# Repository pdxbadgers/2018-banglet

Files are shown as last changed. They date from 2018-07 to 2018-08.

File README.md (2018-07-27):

DEFCON 26 DC503 VIP Banglet
---------------------------
Here we are, another crazy year, another crazy party badge.  Necks are so over-used, so this year we're migrating to the wrist.  The idea is a fully functional bluetooth recon device with multiple, um, "hidden" party modes on the bleuart (like, UART over bluetooth, crazy right?) service.

credits (github/twitter)
------------------------

Original Concept:
* @nishakm / @nishakmr

Board Design:
* @nishakm / @nishakmr
* @r00tkillah

3D Design:
* @jonhannis
* @pierce403 / @deanpierce

PCB necromancers:
* @r00tkillah
* @securelyfitz
* @office_deskjet
* @nishakm / @nishakmr
* @jonhannis

Code monkeys:
* @pierce403 / @deanpierce
* @nishakm / @nishakmr

Special thanks to Adafruit Industries for publishing their board designs, 3D designs and NRF52 Arduino code examples.

And a special thanks to everyone else who donated time, money, or crazy ideas that helped make this possible.

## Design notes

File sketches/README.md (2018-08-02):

Welcome to the 503 Party
------------------------
So, you have a 503 banglet, now what?  You may notice a striking similarity to the Adafruit Feather.  This is because the banglet board is pretty much a Feather modified to fit the banglet form factor. What that means is that A0 is the only data pin you have access to and it goes straight to a neopixel strip. But you still have the whole suite of BT functionality that the Nordic NRF52 SoC has to offer. So you'll have to get creative with encoding your data into blinky lights ;).

Adafruit has a good collection of examples to get you started with writing your custom sketch. You can clone their repo here: https://github.com/adafruit/Adafruit_NRF52_Arduino

These instructions will take you through flashing your own custom arduino sketch to your banglet.

Installing the Feather board definitions
----------------------------------------

Paraphrased from here:

https://learn.adafruit.com/adafruit-feather-32u4-basic-proto/arduino-ide-setup

Download Arduino for your platform:

https://www.arduino.cc/en/Main/Software

In preferences add "Additonal Boards Manager URLs":

https://adafruit.github.io/arduino-board-index/package_adafruit_index.json

Tools > Board > Board Manager

Search for "Adafruit nrf52 by Adafruit"

Install the latest.

Restart Arduino IDE

Toors > Board > Adafruit Feather 32u4

Installing the Neo Pixel library
--------------------------------
To light up the neopixels, you need to install the Neo Pixel libraries.  Luckily you should be able to find it pretty quick in the library manager.

Sketch > Include Libraries > Manage Libraries

Adafruit Neo Pixel

You will need 32 bit glibc
and install nrfutil

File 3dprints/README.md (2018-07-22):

503 Banglet STL files
---------------------

You may notice there is a soft and a hard version.  The soft design was the original design, and has a much more rubbery feel.  The recommended filament for the soft design is the clear flexible filament from 3Dsolutech.com.  This can be a huge pain to print on most 3D printers, so we also made a version of the banglet with a hinge.  This banglet can be printed with standard PLA or ABS.

Once printed, you can press fit or glue magnets into the holes, depending on version printed, and maybe put some 22 gauge wire into the hinge if you printed the hard version.  We have also been using thin bands of 3/4" clear polyolefin heat shrink tubing to hold the electronics in place.

Recommended printer settings:
---------------------------
soft banglet:
```
0.2mm layer height
100% infill
230c extruder temp
```

hard banglet:
```
0.2mm layer height
10% hexagonal infill
230c extruder temp
55-90c bed temp (depends on filament)
```

Big thanks to @jonhannis for leading this effort.

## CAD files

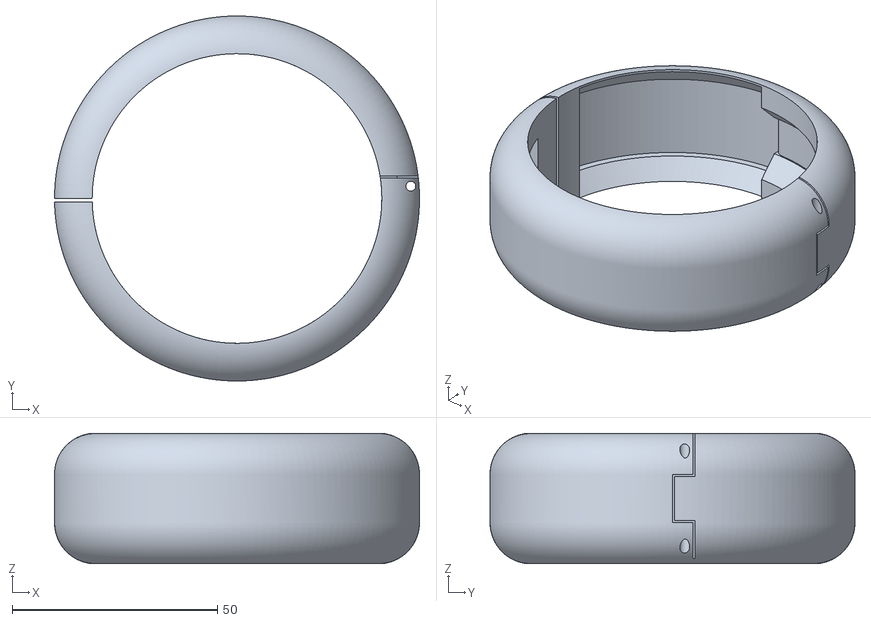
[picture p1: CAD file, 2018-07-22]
3dprints/503banglet-hard.stl
88.9 x 88.9 x 31.8

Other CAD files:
3dprints/503banglet-soft.stl

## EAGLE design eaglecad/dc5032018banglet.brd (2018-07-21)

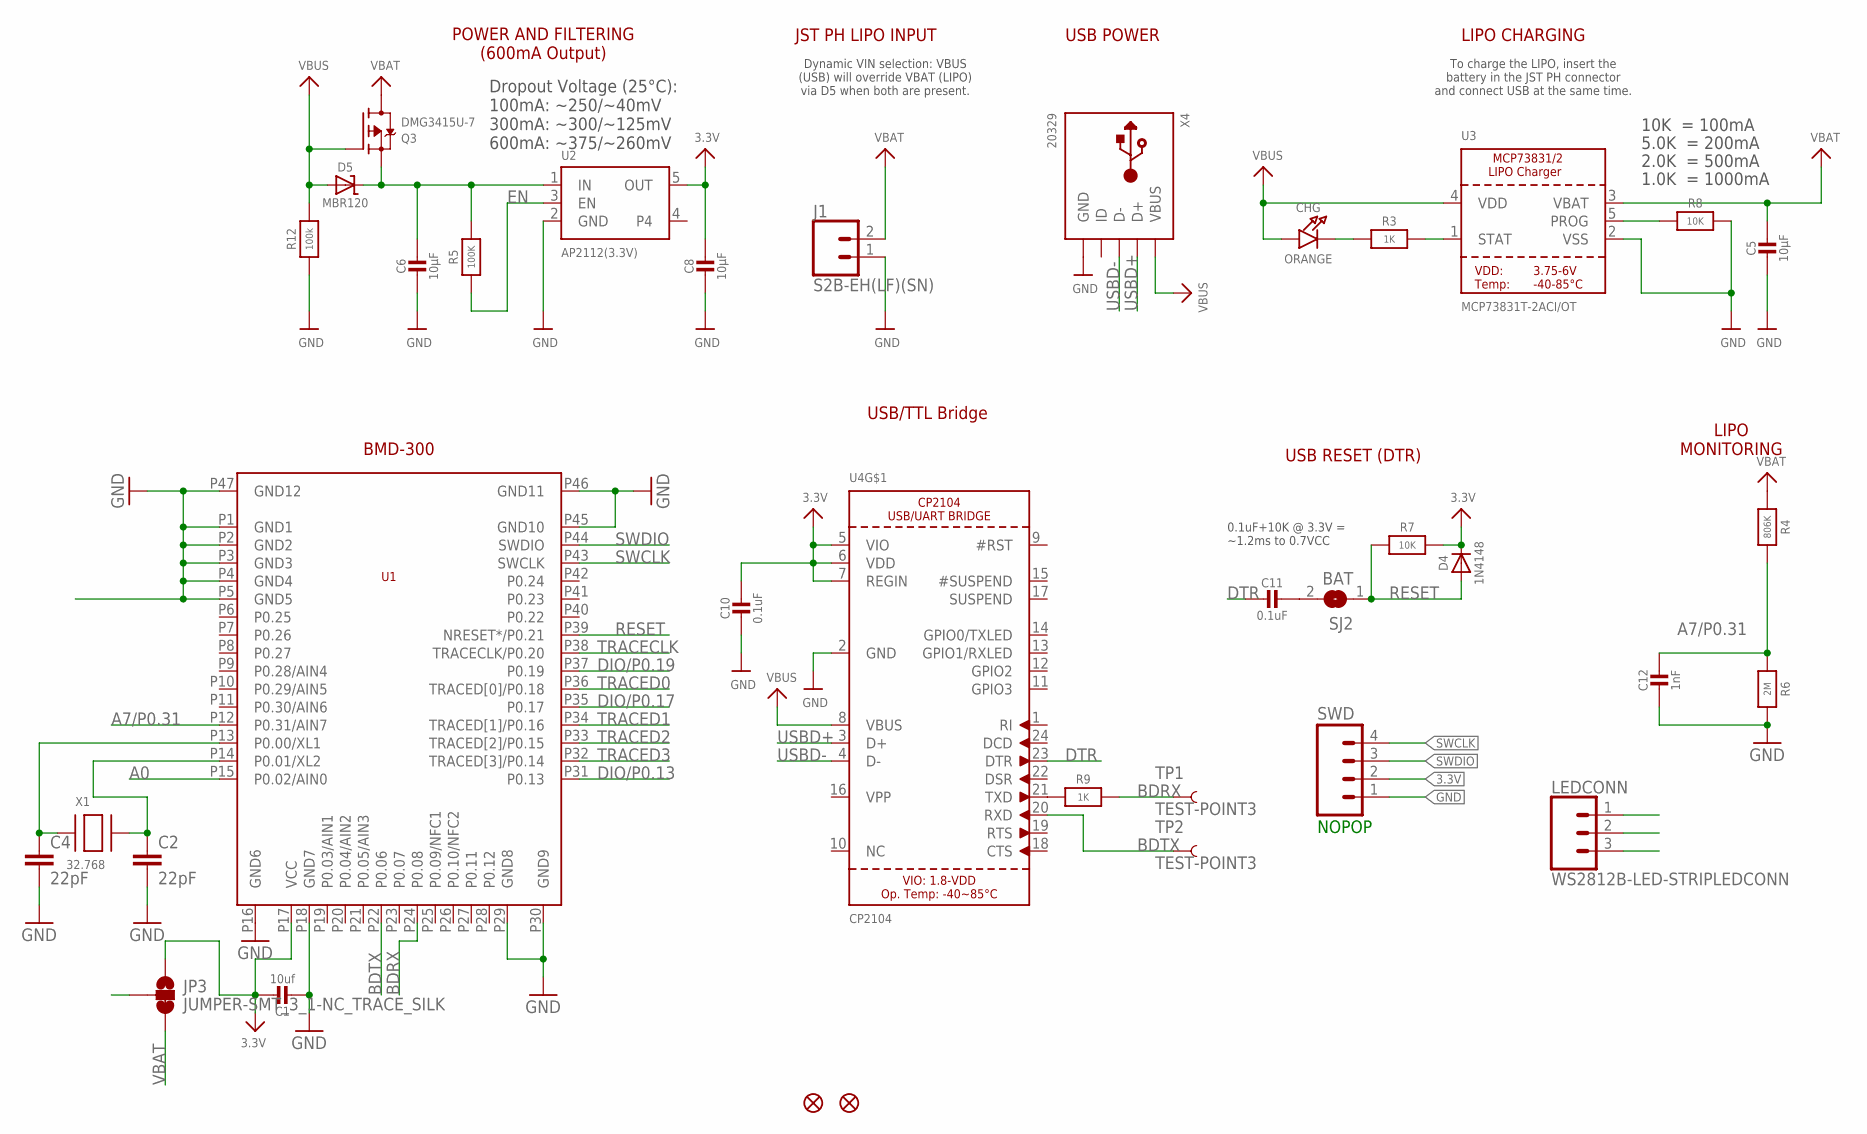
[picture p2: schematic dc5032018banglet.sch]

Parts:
C1: 10uf; 0805-NO
C2, C4: 22pF; 0603
C5, C6, C8: 10µF; 0805-NO
C10, C11: 0.1uF; 0603-NO
C12: 1nF; 0603-NO
CHG: ORANGE; CHIPLED_0805_NOOUTLINE
D4: 1N4148; SOD-323
D5: MBR120; SOD-123
FD1, FD2: FIDUCIALUFIDUCIAL; FIDUCIAL-MICRO
J1: S2B-EH(LF)(SN); 1X2(2.5)
JP3: JUMPER-SMT_3_1-NC_TRACE_SILK; SMT-JUMPER_3_1-NC_TRACE_SILK
LEDCONN: WS2812B-LED-STRIPLEDCONN; 1X3(2.5)
Q3: DMG3415U-7; SOT23-R
R3, R9: 1K; 0603-NO
R4: 806K; 0603-NO
R5: 100K; 0603-NO
R6: 2M; 0603-NO
R7, R8: 10K; 0603-NO
R12: 100k; 0603-NO
SJ2: BAT; SOLDERJUMPER_CLOSEDWIRE
SWD: M04LOCK; 1X04_LOCK@1
TP1, TP2: TEST-POINT3; PAD.03X.03
U1: BMD-300
U2: AP2112(3.3V); SOT23-5
U3: MCP73831T-2ACI/OT; SOT23-5
U4: CP2104; QFN24_4MM_SMSC
X1: 32.768; XTAL3215
X4: 20329; MICRO-USB5+6P-SMD-0.65-B

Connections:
3.3V: C1.1, C8.1, C10.1, D4.C, JP3.1, R7.2, SWD.2, U1.P17 (VCC), U2.5 (OUT), U4.5 (VIO), U4.6 (VDD), U4.7 (REGIN)
A0: LEDCONN.2, U1.P15 (P0.02/AIN0)
A7/P0.31: C12.1, R4.2, R6.1, U1.P12 (P0.31/AIN7)
BDRX: R9.2, TP1.P$1, U1.P24 (P0.08)
BDTX: TP2.P$1, U1.P22 (P0.06), U4.20 (RXD)
DIO/P0.13: U1.P31 (P0.13)
DIO/P0.17: U1.P35 (P0.17)
DIO/P0.19: U1.P37 (P0.19)
DTR: C11.2, U4.23 (DTR)
EN: R5.1, U2.3 (EN)
GND: C1.2, C2.2, C4.2, C5.2, C6.2, C8.2, C10.2, C12.2, J1.1, LEDCONN.3, R6.2, R8.2, R12.1, SWD.1, U1.P1 (GND1), U1.P2 (GND2), U1.P3 (GND3), U1.P4 (GND4), U1.P5 (GND5), U1.P16 (GND6), U1.P18 (GND7), U1.P29 (GND8), U1.P30 (GND9), U1.P45 (GND10), U1.P46 (GND11), U1.P47 (GND12), U2.2 (GND), U3.2 (VSS), U4.2 (GND), X4.5 (GND), X4.S1 (GND), X4.S2 (GND), X4.S3 (GND), X4.S4 (GND), X4.S5 (GND), X4.S6 (GND)
unnamed: C2.1, U1.P14 (P0.01/XL2), X1.P$2
unnamed: C4.1, U1.P13 (P0.00/XL1), X1.P$1
unnamed: CHG.C, R3.1
unnamed: R3.2, U3.1 (STAT)
unnamed: R8.1, U3.5 (PROG)
unnamed: R9.1, U4.21 (TXD)
unnamed: C11.1, SJ2.2
RESET: D4.A, R7.1, SJ2.1, U1.P39 (NRESET*/P0.21)
SWCLK: SWD.4, U1.P43 (SWCLK)
SWDIO: SWD.3, U1.P44 (SWDIO)
TP: U4.THERM (TP)
TRACECLK: U1.P38 (TRACECLK/P0.20)
TRACED0: U1.P36 (TRACED[0]/P0.18)
TRACED1: U1.P34 (TRACED[1]/P0.16)
TRACED2: U1.P33 (TRACED[2]/P0.15)
TRACED3: U1.P32 (TRACED[3]/P0.14)
USBD+: U4.3 (D+), X4.3 (D+)
USBD-: U4.4 (D-), X4.2 (D-)
VBAT: C5.1, J1.2, JP3.3, Q3.3 (D), R4.1, U3.3 (VBAT)
VBUS: CHG.A, D5.A, Q3.1 (G), R12.2, U3.4 (VDD), U4.8 (VBUS), X4.1 (VBUS)
VIN: C6.1, D5.C, Q3.2 (S), R5.2, U2.1 (IN)
VLED: JP3.2, LEDCONN.1

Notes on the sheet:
POWER AND FILTERING (600mA Output)
Dropout Voltage (25°C): 100mA: ~250/~40mV 300mA: ~300/~125mV 600mA: ~375/~260mV
JST PH LIPO INPUT
Dynamic VIN selection: VBUS (USB) will override VBAT (LIPO) via D5 when both are present.
USB POWER
10K = 100mA
5.0K = 200mA
2.0K = 500mA
1.0K = 1000mA
LIPO CHARGING
To charge the LIPO, insert the battery in the JST PH connector and connect USB at the same time.
LIPO MONITORING
USB RESET (DTR)
0.1uF+10K @ 3.3V = ~1.2ms to 0.7VCC
USB/TTL Bridge
NOPOP
BMD-300

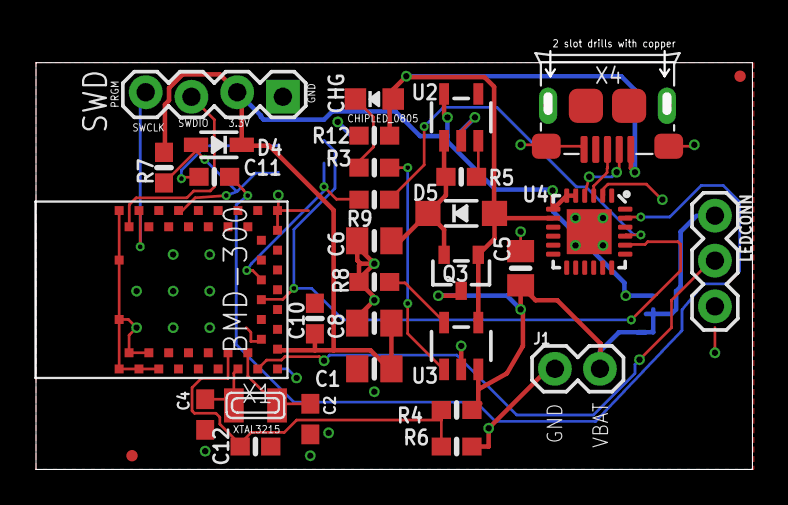
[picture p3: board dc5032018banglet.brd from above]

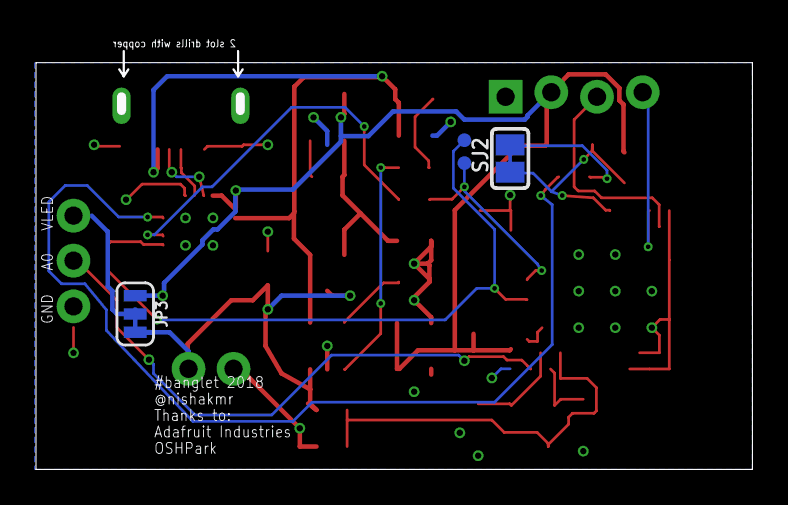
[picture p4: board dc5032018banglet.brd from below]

Board: 2 copper layers, 39.8 x 23.2 mm, 36 parts (4 on the bottom side), 24 nets.

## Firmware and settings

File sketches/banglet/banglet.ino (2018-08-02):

/*********************************************************************
 This is an example for our nRF52 based Bluefruit LE modules

 Pick one up today in the adafruit shop!

 Adafruit invests time and resources providing this open source code,
 please support Adafruit and open-source hardware by purchasing
 products from Adafruit!

 MIT license, check LICENSE for more information
 All text above, and the splash screen below must be included in
 any redistribution
*********************************************************************/

/*********************************************************************
 * Thank you, Adafruit Industries for the examples!
 *
 * This is the sketch that makes the Banglet work
 * It came from https://github.com/pdxbadgers/2018-banglet/
 * There are other sketches there so if you would like to flash the
 * other ones to see what they do or try to hack on your banglet, feel
 * free to clone the project and follow the instructions
 *
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
 * This is meant to be used with either the Adafruit Bluefruit LE app
 * or the Serial Bluetooth Terminal. It takes advantage of Nordic's
 * proprietary UART service, allowing you to interact with the banglet
 * using a 'shell'. You can find these apps at the Android play store
 * (I am not sure about iOS but I am guessing you can find an equivalent)
 *
 * Once you connect to the banglet, you can list all the commands by sending
 * '/list' through the terminal.
 *
 * Happy Hacking!
 ************************************************************************/

#include <bluefruit.h>
#include <Adafruit_NeoPixel.h>
#include "wdt.h"
#include "CRC32.h"

/*
 * Global
 */

// BLE Service
BLEUart bleuart;

String mode="scan"; // set the default mode

// BT device scan
uint seen=0;
const byte MAX_MACS = 24;
uint8_t* seen_macs[MAX_MACS];
uint8_t* seen_names[MAX_MACS];


// neopixel
#define N_LEDS 12
#define PIN    A0

Adafruit_NeoPixel strip = Adafruit_NeoPixel(N_LEDS, PIN, NEO_GRB + NEO_KHZ800);

// unique names
const String direc[] = {"NE",
                        "NW",
                        "SE",
                        "SW",
                        "N",
                        "S",
                        "E",
                        "W"};

const String loc[] = {"Alder",
                      "Burnside",
                      "Couch",
                      "Davis",
                      "Everett",
                      "Flanders",
                      "Glisan",
                      "Hoyt",
                      "Irving",
                      "Johnson",
                      "Kirby",
                      "Lovejoy",
                      "Marshall",
                      "Northrup",
                      "Overton",
                      "Pettygrove",
                      "Quimby",
                      "Raleigh",
                      "Savier",
                      "Thurman",
                      "Upshur",
                      "Vaughn",
                      "Wilson",
                      "York"};

const String st[] = {"Street",
                     "Avenue",
                     "Way",
                     "Place"};

/*
 * Initial setup
 */
void setup()
{
  // turn off watchdog during setup
  wdt_disable();
  
  // setup serial
  Serial.begin(115200);
  Serial.println("Welcome to your Banglet!");
  Serial.println("---------------------------\n");


  // create banglet's name
  char* uniqueID = (char*)getMcuUniqueID();
  Serial.printf("id: %s\r\n",uniqueID);
  uint32_t checksum = CRC32::calculate((const char*)(uniqueID), strlen(uniqueID));
  Serial.printf("checksum: %u\r\n",checksum);
  randomSeed(checksum);
  
  String leading = "503 ";
  String banglet_name = leading + direc[random(0, 8)] + " " + loc[random(0,24)] + " " + st[random(0, 4)];
  char char_b_name[30];
  banglet_name.toCharArray(char_b_name, 30);
  Serial.printf("name: %s\r\n",char_b_name);
  Serial.println();

  // setup strip
  stripInit();

  // allocate some buffers
  for(int i=0;i<MAX_MACS;++i)
  {
    uint8_t* new_thing = new uint8_t[6];
    uint8_t* new_name  = new uint8_t[32];
    memset(new_thing,0,6);
    memset(new_name,0,32);
    seen_macs[i]=new_thing;
    seen_names[i]=new_name;
  }

  // Config the peripheral connection with maximum bandwidth
  // more SRAM required by SoftDevice
  // Note: All config***() function must be called before begin()
  Bluefruit.configPrphBandwidth(BANDWIDTH_MAX);

  Bluefruit.begin();
  // Set max power. Accepted values are: -40, -30, -20, -16, -12, -8, -4, 0, 4
  Bluefruit.setTxPower(4);
  Bluefruit.setName(char_b_name);
  Bluefruit.setConnectCallback(connect_callback);
  Bluefruit.setDisconnectCallback(disconnect_callback);

  // Start Central Scan
  Bluefruit.setConnLedInterval(250);
  Bluefruit.Scanner.setRxCallback(scan_callback);
  //Bluefruit.Scanner.filterRssi(-80);
  Bluefruit.Scanner.start(0);

  // Configure and Start BLE Uart Service
  bleuart.begin();

  // Set up and start advertising
  startAdv();

  Serial.println("Please use the Adafruit Bluefruit app or the Serial Bluetooth Terminal app to connect to the Banglet");
  Serial.println("Once connected, send /list for a list of commands you can send");

  // set up the watchdog
  wdt_enable(WDTO_8S);
}

// advertise peripheral BLEUART service
void startAdv(void)
{
  // Advertising packet
  Bluefruit.Advertising.addFlags(BLE_GAP_ADV_FLAGS_LE_ONLY_GENERAL_DISC_MODE);
  Bluefruit.Advertising.addTxPower();

  // Include bleuart 128-bit uuid
  Bluefruit.Advertising.addService(bleuart);

  // Secondary Scan Response packet (optional)
  // Since there is no room for 'Name' in Advertising packet
  Bluefruit.ScanResponse.addName();

  /* Start Advertising
   * - Enable auto advertising if disconnected
   * - Interval:  fast mode = 20 ms, slow mode = 152.5 ms
   * - Timeout for fast mode is 30 seconds
   * - Start(timeout) with timeout = 0 will advertise forever (until connected)
   *
   * For recommended advertising interval
   * https://developer.apple.com/library/content/qa/qa1931/_index.html
   */
  Bluefruit.Advertising.restartOnDisconnect(true);
  Bluefruit.Advertising.setInterval(32, 244);    // in unit of 0.625 ms
  Bluefruit.Advertising.setFastTimeout(30);      // number of seconds in fast mode
  Bluefruit.Advertising.start(0);                // 0 = Don't stop advertising after n seconds
}

// show that the strip is on
void stripInit(){
  strip.begin();
  strip.setBrightness(16);
  for(int i=0;i<strip.numPixels(); i++){
    strip.setPixelColor(i, strip.Color(255, 0, 0));
    strip.show();
    delay(100);
    strip.setPixelColor(i, strip.Color(0, 0, 0));
    strip.show();
  }
}


// find mac addresses
int find_mac(uint8_t* mac)
{
  for(int i=0;i<seen;++i)
  {
    if(0==memcmp(mac,seen_macs[i],6))
    {
      return i;
    }
  }
  //seen_macs[seen]=mac;
  memcpy(seen_macs[seen%MAX_MACS],mac,6);
  seen++;

  return seen-1;
}

// scan callback function which prints out mac
// addresses in a readable way
void scan_callback(ble_gap_evt_adv_report_t* report)
{
  uint8_t new_thing[6];
  memcpy(new_thing,report->peer_addr.addr,6);
  //Serial.println("copied MAC buffer");

  // which device is this?
  //Serial.println("finding thing");
  int thing = find_mac(new_thing);
  //Serial.printf("found thing %d\n",thing);

  uint8_t new_name[32];
  memset(new_name,0,32);
  if(Bluefruit.Scanner.parseReportByType(report, BLE_GAP_AD_TYPE_COMPLETE_LOCAL_NAME, new_name, 32))
  {
    if(strlen((char*)new_name)>0)
    {
      memset(seen_names[thing],0,32);
      memcpy(seen_names[thing],new_name,32);
    }
  }

}


/*
 * Loop function
 * Read bytes send from UART app and do stuff with it
 */
void loop()
{
  wdt_reset(); // kick the watchdog timer
  delay(200);  // short nap
  
  // Forward from BLEUART to HW Serial
  while ( bleuart.available() )
  {
    char rx_buf[64];
    memset(rx_buf,0,sizeof(rx_buf));
    int rx_size = bleuart.read(rx_buf, sizeof(rx_buf));
    String command = String(rx_buf);
    command.trim();
    parseCommand(command);
  }

  if(mode.equals("scan"))btscan();
  else if(mode.equals("rainbow"))rainbow(10, 1);
  else if(mode.equals("patriot"))patriot();
  else if(mode.equals("off"))turnOff();
  else if(mode.equals("frozen"))blueScaleFade(200);
  else if(mode.equals("fire"))redScaleFade(200);
  else btscan(); // I guess scan should be the default

  // Request CPU to enter low-power mode until an event/interrupt occurs
  waitForEvent();
}

// UART service connect callback
void connect_callback(uint16_t conn_handle)
{
  char central_name[32] = { 0 };
  Bluefruit.Gap.getPeerName(conn_handle, central_name, sizeof(central_name));

  Serial.print("Connected to ");
  Serial.println(central_name);
  //listCommands();
}

// UART service disconnect callback
void disconnect_callback(uint16_t conn_handle, uint8_t reason)
{
  (void) conn_handle;
  (void) reason;

  Serial.println();
  Serial.println("Disconnected");
}

/*
 * Main Banglet functions that parses the send messages and does things with it
 */
void parseCommand(String command)
{
  if(command.equals("help"))listCommands();
  else if(command.equals("devices"))listDevices();
  else if(command.equals("count"))numDevices();
  else if(command.equals("modes"))listModes();

  // some LED modes
  else if(command.equals("scan"))scan();
  else if(command.equals("off"))off();
  else if(command.equals("rainbow"))rainbow();
  else if(command.equals("patriot"))setPatriot();
  else if(command.equals("frozen"))frozen();
  else if(command.equals("fire"))fire();

  // just for fun
  else if(command.equals("id")){bleuart.write("uid=0(root) gid=0(root)");bleuart.write("groups=0(root)\n");}

  // brightness options
  else if(command.equals("bright"))strip.setBrightness(16);
  else if(command.equals("brighter"))strip.setBrightness(32);
  else if(command.equals("brightest"))strip.setBrightness(64);
  else if(command.equals("blinding"))strip.setBrightness(128);
  else
  {
    bleuart.write("Unknown command, ");
    bleuart.write("type 'help' for help.\n");
  }
  bleuart.write("\n# ");
}

/*
 * All the things Banglet can do
 * You can either hack these or add your function here
 */

// list all commands
void listCommands()
{
  bleuart.write("help: You're looking");
  bleuart.write(" at it.\n");

  bleuart.write("devices: List known");
  bleuart.write(" devices.\n");

  bleuart.write("count: List number of");
  bleuart.write(" devices.\n");

  bleuart.write("modes: List banglet");
  bleuart.write(" display modes.\n");
}

// list all modes
void listModes()
{
  bleuart.write("scan: Show bt");
  bleuart.write(" devices.\n");
  bleuart.write("off: No lights.\n");

  if(seen<5)
  {
    bleuart.write("????: Unlock at level 5.\n");
    bleuart.write("Collect more BT devices to unlock modes!");
    return;
  }

  bleuart.write("patriot: OMG USA!\n");
  
  if(seen<10)
  {
    bleuart.write("????: Unlock at level 10.\n");
    bleuart.write("Collect more BT devices to unlock modes!");
    return;
  }

  bleuart.write("rainbow: Blink the rainbow!\n");

  if(seen<15)
  {
    bleuart.write("????: Unlock at level 15.\n");
    bleuart.write("Collect more BT devices to unlock modes!");
    return;
  }

  bleuart.write("frozen: Only one way");
  bleuart.write(" to find out.\n");

  if(seen<20)
  {
    bleuart.write("????: Unlock at level 20.\n");
    bleuart.write("Collect more BT devices to unlock modes!");
    return;
  }

  bleuart.write("fire: Halt and");
  bleuart.write(" catch fire.\n");

  if(seen<30)
  {
    bleuart.write("bright/brighter");
    bleuart.write("/brightest\n");
    return;
  }
  if(seen<50)
  {
    bleuart.write("blinding\n");
  }
}


void setPatriot()
{
  bleuart.write("USA! USA!\n");
  mode="patriot";
}

// red, white and blue lights
int patriot_counter=0;
void patriot()
{
  // light up strip with red, white and blue
  uint32_t red=strip.Color(255,0,0);
  uint32_t white=strip.Color(255,255,255);
  uint32_t blue=strip.Color(0,0,255);

  for (int i = 0; i < strip.numPixels(); i+=3)
  {
    strip.setPixelColor((i+patriot_counter)%15,red);
    strip.setPixelColor((i+patriot_counter+1)%15,white);
    strip.setPixelColor((i+patriot_counter+2)%15,blue);
  }

  patriot_counter = (patriot_counter+1)%3;

  strip.show();
  delay(200);
}

// rainbow lights
void rainbow()
{
  bleuart.write("Ooo! Rainbow!\n");
  bleuart.flush();
  mode="rainbow";
}

void rainbow(uint8_t wait, int rainbowLoops)
{
  uint32_t wheelVal;
  int redVal, greenVal, blueVal;

  for(int k = 0 ; k < rainbowLoops ; k ++){

    for(int j=0; j<256; j++) { // 5 cycles of all colors on wheel

      for(int i=0; i< strip.numPixels(); i++) {

        wheelVal = Wheel(((i * 256 / strip.numPixels()) + j) & 255);

        redVal = red(wheelVal);
        greenVal = green(wheelVal);
        blueVal = blue(wheelVal);

        strip.setPixelColor( i, strip.Color( redVal, greenVal, blueVal ) );

      }

        strip.show();
        delay(wait);
    }

  }
}

// Input a value 0 to 255 to get a color value.
// The colours are a transition r - g - b - back to r.
uint32_t Wheel(byte WheelPos) {
  WheelPos = 255 - WheelPos;
  if(WheelPos < 85) {
    return strip.Color(255 - WheelPos * 3, 0, WheelPos * 3,0);
  }
  if(WheelPos < 170) {
    WheelPos -= 85;
    return strip.Color(0, WheelPos * 3, 255 - WheelPos * 3,0);
  }
  WheelPos -= 170;
  return strip.Color(WheelPos * 3, 255 - WheelPos * 3, 0,0);
}

uint8_t red(uint32_t c) {
  return (c >> 16);
}
uint8_t green(uint32_t c) {
  return (c >> 8);
}
uint8_t blue(uint32_t c) {
  return (c);
}

// turn the lights off if they get annoying
void off()
{
  bleuart.write("Turning off the lights\n");
  mode="off";
}

void turnOff()
{
  for(int i=0; i<strip.numPixels(); i++)
  {
    strip.setPixelColor(i, 0, 0, 0);
  }
  strip.show();
}

// scan close by BT devices
void scan()
{
  turnOff();
  bleuart.write("Showing nearby ");
  bleuart.write("bluetooth devices...\n");
  bleuart.flush();
  mode="scan";
}

void btscan()
{
  int first=0;
  if(seen>12)first=seen-12;

  for ( uint i=0 ; i < 12; ++i)
  {
    uint32_t color=0;

    if(i>seen)color=strip.Color(0,0,0);
    else color = strip.Color(seen_macs[(first+i)%MAX_MACS][5],seen_macs[(first+i)%MAX_MACS][4],seen_macs[(first+i)%MAX_MACS][3]);
    strip.setPixelColor(i, color);
  }

  strip.show();
}

//frozen
void frozen()
{
  bleuart.write("Let it go!\n");
  bleuart.flush();
  mode="frozen";
}

void blueScaleFade(uint8_t wait)
{
  //loop through fade values

  // divide the neopixel strip into 3 equal parts
  for(int i=0; i< strip.numPixels(); i=i+3)
  {
    // find a color for this set
     uint32_t color = strip.Color(random(0, 181), random(0, 256), random(100, 256));
     // set the color
     for(int j=i; j<i+3; j++)
     {
        if(j<strip.numPixels())
        {
          strip.setPixelColor(j, color);
        }
     }
  }
  strip.show();
  delay(wait);
}

//frozen
void fire()
{
  bleuart.write("Flame on!\n");
  bleuart.flush();
  mode="fire";
}


void redScaleFade(uint8_t wait)
{
  //loop through fade values

  // divide the neopixel strip into 3 equal parts
  for(int i=0; i< strip.numPixels(); i=i+3)
  {
    // find a color for this set
     uint32_t color = strip.Color(random(192, 256), random(0, 64), random(0, 32));
     // set the color
     for(int j=i; j<i+3; j++)
     {
        if(j<strip.numPixels())
        {
          strip.setPixelColor(j, color);
        }
     }
  }
  strip.show();
  delay(wait);
}

//show device names
void listDevices()
{
  for ( int i = 0 ; i < seen; ++i)
  {
    char macbuf[20];
    char namebuf[32];
    memset(macbuf,0,20);
    memset(namebuf,0,32);

    sprintf(macbuf,"%02X:%02X:%02X:%02X:%02X:%02X ",seen_macs[i][5],seen_macs[i][4],seen_macs[i][3],seen_macs[i][2],seen_macs[i][1],seen_macs[i][0]);
    sprintf(namebuf,"%s\n",seen_names[i]);
    Serial.printBufferReverse(seen_macs[i], 6, ':');

    bleuart.write(macbuf);
    bleuart.write(namebuf);
  }
}

//show number of devices
void numDevices()
{
  char outbuf[20];
  memset(outbuf,0,20);
  sprintf(outbuf,"Devices Seen: %d\n",seen);
  bleuart.write(outbuf);
}

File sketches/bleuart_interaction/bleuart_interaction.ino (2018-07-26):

/*********************************************************************
 This is an example for our nRF52 based Bluefruit LE modules

 Pick one up today in the adafruit shop!

 Adafruit invests time and resources providing this open source code,
 please support Adafruit and open-source hardware by purchasing
 products from Adafruit!

 MIT license, check LICENSE for more information
 All text above, and the splash screen below must be included in
 any redistribution
*********************************************************************/
#include <bluefruit.h>
#include <Adafruit_NeoPixel.h>

// BLE Service
BLEUart bleuart;

// List of commands
const int MAX_COMM_LEN = 10;
const int MAX_COMM = 4;
const char commands[MAX_COMM][MAX_COMM_LEN] = {"list", "rainbow", "patriot", "off"};

// neopixel setup
#define N_LEDS 10
#define PIN    A0
Adafruit_NeoPixel strip = Adafruit_NeoPixel(N_LEDS, PIN, NEO_GRB + NEO_KHZ800);

uint32_t color = 0;

byte neopix_gamma[] = {
    0,  0,  0,  0,  0,  0,  0,  0,  0,  0,  0,  0,  0,  0,  0,  0,
    0,  0,  0,  0,  0,  0,  0,  0,  0,  0,  0,  0,  1,  1,  1,  1,
    1,  1,  1,  1,  1,  1,  1,  1,  1,  2,  2,  2,  2,  2,  2,  2,
    2,  3,  3,  3,  3,  3,  3,  3,  4,  4,  4,  4,  4,  5,  5,  5,
    5,  6,  6,  6,  6,  7,  7,  7,  7,  8,  8,  8,  9,  9,  9, 10,
   10, 10, 11, 11, 11, 12, 12, 13, 13, 13, 14, 14, 15, 15, 16, 16,
   17, 17, 18, 18, 19, 19, 20, 20, 21, 21, 22, 22, 23, 24, 24, 25,
   25, 26, 27, 27, 28, 29, 29, 30, 31, 32, 32, 33, 34, 35, 35, 36,
   37, 38, 39, 39, 40, 41, 42, 43, 44, 45, 46, 47, 48, 49, 50, 50,
   51, 52, 54, 55, 56, 57, 58, 59, 60, 61, 62, 63, 64, 66, 67, 68,
   69, 70, 72, 73, 74, 75, 77, 78, 79, 81, 82, 83, 85, 86, 87, 89,
   90, 92, 93, 95, 96, 98, 99,101,102,104,105,107,109,110,112,114,
  115,117,119,120,122,124,126,127,129,131,133,135,137,138,140,142,
  144,146,148,150,152,154,156,158,160,162,164,167,169,171,173,175,
  177,180,182,184,186,189,191,193,196,198,200,203,205,208,210,213,
  215,218,220,223,225,228,231,233,236,239,241,244,247,249,252,255 };

void setup()
{
  Serial.begin(115200);
  Serial.println("Welcome to the Banglet!");
  Serial.println("---------------------------\n");

  // Config the peripheral connection with maximum bandwidth 
  // more SRAM required by SoftDevice
  // Note: All config***() function must be called before begin()
  Bluefruit.configPrphBandwidth(BANDWIDTH_MAX);

  Bluefruit.begin();
  // Set max power. Accepted values are: -40, -30, -20, -16, -12, -8, -4, 0, 4
  Bluefruit.setTxPower(4);
  Bluefruit.setName("Banglet");
  //Bluefruit.setName(getMcuUniqueID()); // useful testing with multiple central connections
  Bluefruit.setConnectCallback(connect_callback);
  Bluefruit.setDisconnectCallback(disconnect_callback);

  // Configure and Start BLE Uart Service
  bleuart.begin();

  // Set up and start advertising
  startAdv();

  Serial.println("Please use the Serial Bluetooth Terminal app to connect to the Banglet");
  Serial.println("Once connected, send LIST for a list of commands to send");
}

void startAdv(void)
{
  // Advertising packet
  Bluefruit.Advertising.addFlags(BLE_GAP_ADV_FLAGS_LE_ONLY_GENERAL_DISC_MODE);
  Bluefruit.Advertising.addTxPower();

  // Include bleuart 128-bit uuid
  Bluefruit.Advertising.addService(bleuart);

  // Secondary Scan Response packet (optional)
  // Since there is no room for 'Name' in Advertising packet
  Bluefruit.ScanResponse.addName();
  
  /* Start Advertising
   * - Enable auto advertising if disconnected
   * - Interval:  fast mode = 20 ms, slow mode = 152.5 ms
   * - Timeout for fast mode is 30 seconds
   * - Start(timeout) with timeout = 0 will advertise forever (until connected)
   * 
   * For recommended advertising interval
   * https://developer.apple.com/library/content/qa/qa1931/_index.html   
   */
  Bluefruit.Advertising.restartOnDisconnect(true);
  Bluefruit.Advertising.setInterval(32, 244);    // in unit of 0.625 ms
  Bluefruit.Advertising.setFastTimeout(30);      // number of seconds in fast mode
  Bluefruit.Advertising.start(0);                // 0 = Don't stop advertising after n seconds  
}

void loop()
{
  // Forward data from HW Serial to BLEUART
  while (Serial.available())
  {
    // Delay to wait for enough input, since we have a limited transmission buffer
    delay(2);

    uint8_t buf[64];
    int count = Serial.readBytes(buf, sizeof(buf));
    bleuart.write( buf, count );
  }

  // Forward from BLEUART to HW Serial
  while ( bleuart.available() )
  {
    uint8_t rx_buf[64];
    int rx_size = bleuart.read(rx_buf, sizeof(rx_buf));
    parseCommand(rx_buf, rx_size);
  }

  // Request CPU to enter low-power mode until an event/interrupt occurs
  waitForEvent();
}

void connect_callback(uint16_t conn_handle)
{
  char central_name[32] = { 0 };
  Bluefruit.Gap.getPeerName(conn_handle, central_name, sizeof(central_name));

  Serial.print("Connected to ");
  Serial.println(central_name);
}

void disconnect_callback(uint16_t conn_handle, uint8_t reason)
{
  (void) conn_handle;
  (void) reason;

  Serial.println();
  Serial.println("Disconnected");
}

/**
 * Code that banglet uses
 */

void parseCommand(uint8_t *buf, int bufsize)
{
  //for(int i=0; i<bufsize; i++){
  //  Serial.write(buf[i]); 
  //}
  if(buf[0] == '/'){
    int index = getCommand(buf);
    if(index != -1)
    {
      doOption(index);
    }else{
      bleuart.write("Invalid option\n");
    }
  }else{
    bleuart.write("This is not a command\n");
  }
}

int getCommand(uint8_t *buf)
{
  int buf_end = 1;
  while(buf[buf_end] != '\n')
  {
   // Serial.println((char)buf[buf_end]);
    buf_end++;
  }
  // for some reason there are some undetermined characters at the end
  // so shortend the length by this amount which is was found out through
  // experimentation - yes I don't know what is going on here
  buf_end = buf_end - 2;
  //Serial.println(buf_end);
  
  //go through each command
  for(int i=0; i<MAX_COMM; i++)
  {
    //Serial.println(commands[i]);
    //Serial.println((char *)buf);
    //check if the buffer command is the same
    if(strncmp(commands[i], (char *)++buf, buf_end) == 0)
    {
      return i;
    }else{
      --buf;
    }
  }

  return -1;
}

void doOption(int index)
{
  if(index == 0) listCommands();
  if(index == 1) rainbow();
  if(index == 2) patriot();
  if(index == 3) off();
}

void listCommands()
{
  bleuart.write("List of commands:\n");
  for(int i=0; i<MAX_COMM; i++)
  {
    bleuart.write(commands[i]);
    bleuart.write('\n');
  }
}
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

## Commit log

2018-07-21 Added board files and color picker sketch
    Also moved btmonitor.ino to a folder because arduino IDE wants it
    there
    [dc5032018banglet.brd, dc5032018banglet.sch]
2018-07-22 basic board instructions
2018-07-22 make STL directory
2018-07-22 add rubbery banglet
    [banglettt.stl]
2018-07-22 added the hard banglet
    [pla_banglet2.stl]
2018-07-22 renaming some 3d print stuff
    [503banglet-hard.stl, 503banglet-soft.stl]
2018-07-26 Added bluart interaction sketch
    Also moved patriot.ino into patriot folder so arduino won't
    yell
    [bleuart_interaction.ino, patriot.ino]
2018-07-26 Can now list, patriot, rainbow and off
    Also moved the lonely sketch to the arduino likey folder.
    Rainbow needs some work
2018-07-28 transitioned to static buffers, fixed dumb find_mac bug
    [blinkenshellz.ino]
2018-07-28 Tweeks: send UART messages 28 bytes at a time
2018-07-28 make it so device names don't go away
2018-07-30 Replaced Sherlock name with PDXish street names
    [banglet.ino]
2018-07-30 Modified BT scan buffers and printing
2018-07-30 Added listing device names
2018-07-30 Added listing number of devices logged
2018-07-30 Increasing LED number to 12
2018-08-01 switch commands to array of String objects
2018-08-01 Fixed devices and counts command printing in a loop
    [banglet.ino]
2018-08-01 cleaned up command parsing a bit, switched to root shell
2018-08-01 whitespace
    To stop living like a heathen and use a real editor,
    file->preferences->use external editor. Then edit with your OneTrueTextEditor.
2018-08-01 add watchdog timer library
2018-08-01 fixed seeding by seeding with crc32 of unique ID
    [banglet.ino]

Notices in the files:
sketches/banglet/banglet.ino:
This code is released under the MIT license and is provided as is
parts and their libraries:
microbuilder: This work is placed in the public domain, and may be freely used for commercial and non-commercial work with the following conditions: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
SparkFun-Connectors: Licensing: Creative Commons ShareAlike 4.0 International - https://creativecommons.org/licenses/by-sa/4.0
